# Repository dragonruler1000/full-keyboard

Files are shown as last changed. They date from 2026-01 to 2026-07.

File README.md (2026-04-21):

# full-keyboard
This is a 108 key keyboard that follows the ansi 104 key layout with 4 extra keys above the numpad. It has spots for two rotary encoders and a oled but to start i am going to not include those to reduce cost.

I wanted to make this to allow me to try a mechanical keyboard without needing to spend $200+ for a lowend mechanical keyboard and to give a chance to use QMK firmware.

To make this keyboard for your self upload the gerbers in [/PCB](/PCB) to your prefered pcb site. the case is split into 2 parts the files are in [/CAD](/CAD). firmware is built like any qmk firmware. instructions are in the folder as well. other parts are listed below and in BOM.csv and BOM.ods
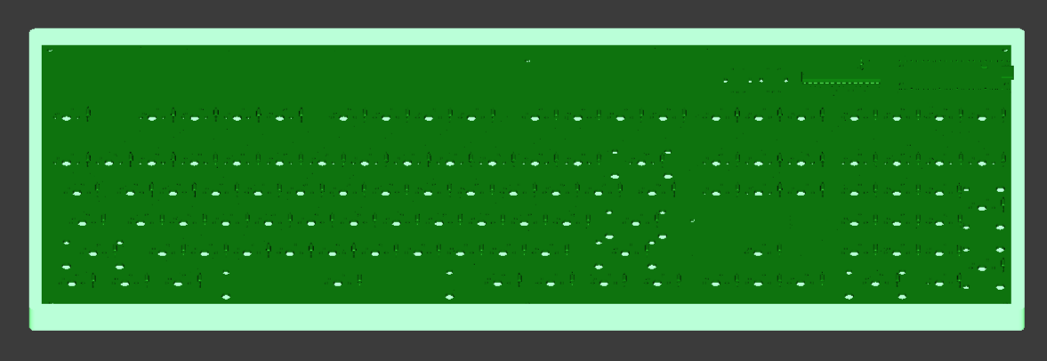
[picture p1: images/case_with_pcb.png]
keyboard in case

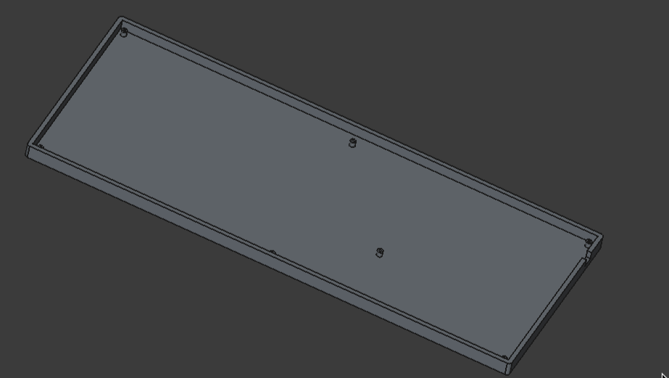
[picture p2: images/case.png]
case

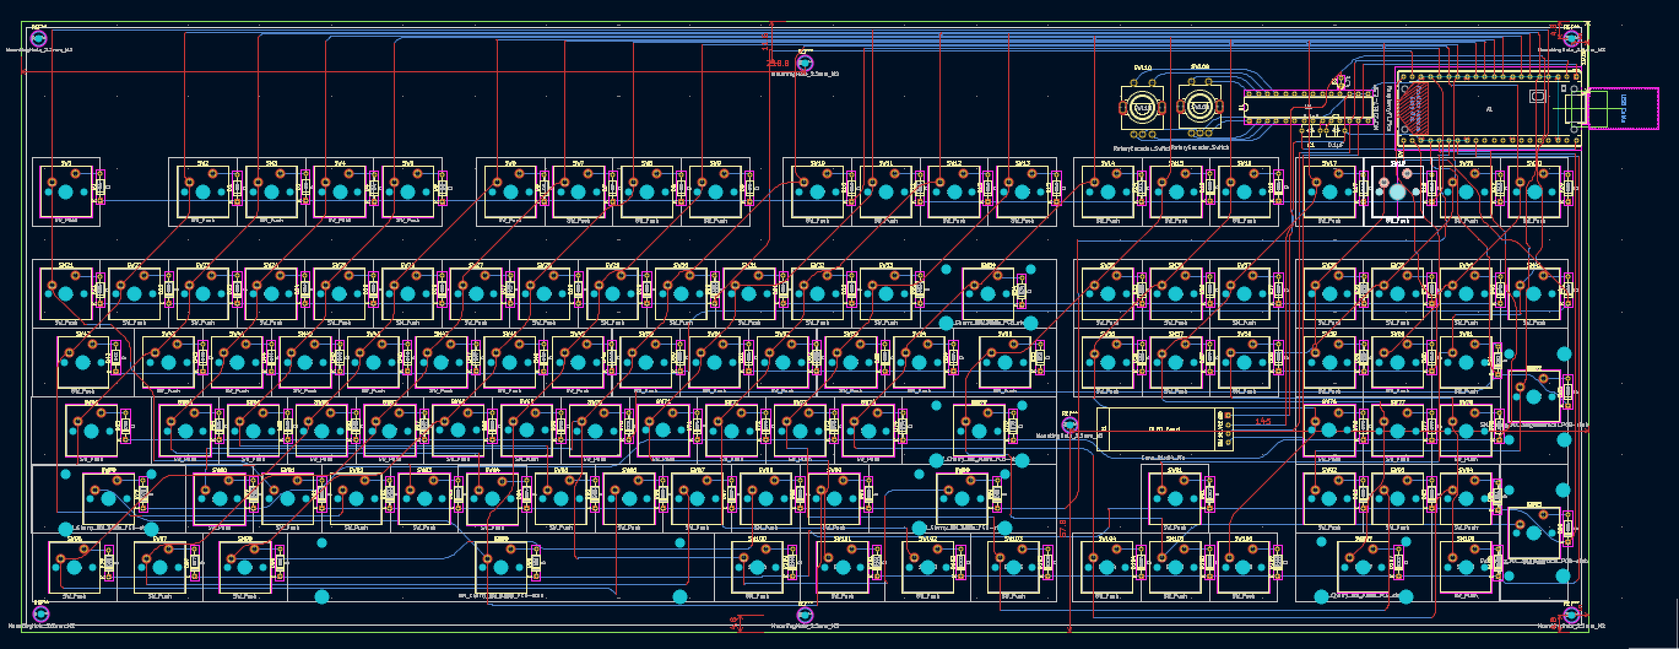
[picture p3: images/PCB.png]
keyboard PCB


Fully soldered keyboard (just need to get the case and keycaps).


BOM:
| Item Count | item name | Unit price $ | Total Price* | Price with discounts* | Link | Running total $* | Running total with coupons* | part number | Notes |
|---|---|---|---|---|---|---|---|---|---|
| 1 | Raspi pico | 5 | 5 | 5 | https://www.adafruit.com/product/5525 | 5.3 | 5.3 | 1 | |
| 110 | 1N4148-t50A diode | 0.0307 | 3.38 | 3.38 | https://www.lcsc.com/product-detail/C895215.html | 8.88 | 8.88 | 2 | packs of 10 |
| 108 | keycaps | 0 | 0 | 0 | https://www.printables.com/model/118708-simple-cherry-mx-keycap | 8.88 | 8.88 | 3 | 1g each can print myself |
| 1 | Outemu(Gaote) Blue Switches  | 21.99 | 21.99 | 21.99 | https://www.amazon.com/gp/product/B0CBSL2Z75 | 32.19 | 32.19 | 4 | pack of 108 price |
| 1 | DUROCK PCB mount stabalizers | 17.99 | 17.99 | 17.99 | https://www.amazon.com/gp/product/B0B2RVN19F?psc=1 | 51.26 | 51.26 | 5 | full set |
| 1 | heatset inserts | 8.99 | 8.99 | 8.99 | https://www.amazon.com/gp/product/B0CS6XJSSL | 60.79 | 60.79 | 6 | |
| 1 | PCB | 35.3 | 35.3 | 35.3 | https://www.jlcpcb.com | 98.21 | 98.21 | 7 | jlcpcb price is cheaper then pcbway before shipping |
| 1 | case | 0 | 0 | 0 | N/A | 98.21 | 98.21 | 8 | print using printing legion |
| 1 | Shipping for PCB | 41.4 | 41.4 | 22.16 | N/A | 142.09 | 121.7 | | First shipping cost is for DHL express second one is for GDL |
| 1 | digikey shipping and tarrifs | 5.36 | 5.36 | 5.36 | N/A | 147.77 | 127.38 | | ±$5 |
| 1 | Adafruit shipping | 5.72 | 5.72 | 5.72 | N/A | 153.83 | 133.44 | | |
| 1 | amazon shipping | 0 | 0 | 0 | N/A | 153.83 | 133.44 | | over min amount for free shipping/have a 30 trial of amazon prime |
| | | | | | | | | | |
| | | | | | | | *Rounded to two decimal places | | |

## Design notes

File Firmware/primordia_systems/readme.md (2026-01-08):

# primordia_systems

primordia_systems

*A short description of the keyboard/project*

* Keyboard Maintainer: [Zachariah Jackson](https://github.com/dragonruler1000)
* Hardware Supported: *The PCBs, controllers supported*
* Hardware Availability: *Links to where you can find this hardware*

Make example for this keyboard (after setting up your build environment):

    make primordia_systems:default

Flashing example for this keyboard:

    make primordia_systems:default:flash

See the [build environment setup](https://docs.qmk.fm/#/getting_started_build_tools) and the [make instructions](https://docs.qmk.fm/#/getting_started_make_guide) for more information. Brand new to QMK? Start with our [Complete Newbs Guide](https://docs.qmk.fm/#/newbs).

## Bootloader

Enter the bootloader in 3 ways:

* **Bootmagic reset**: Hold down the key at (0,0) in the matrix (usually the top left key or Escape) and plug in the keyboard
* **Physical reset button**: Briefly press the button on the back of the PCB - some may have pads you must short instead
* **Keycode in layout**: Press the key mapped to `QK_BOOT` if it is available

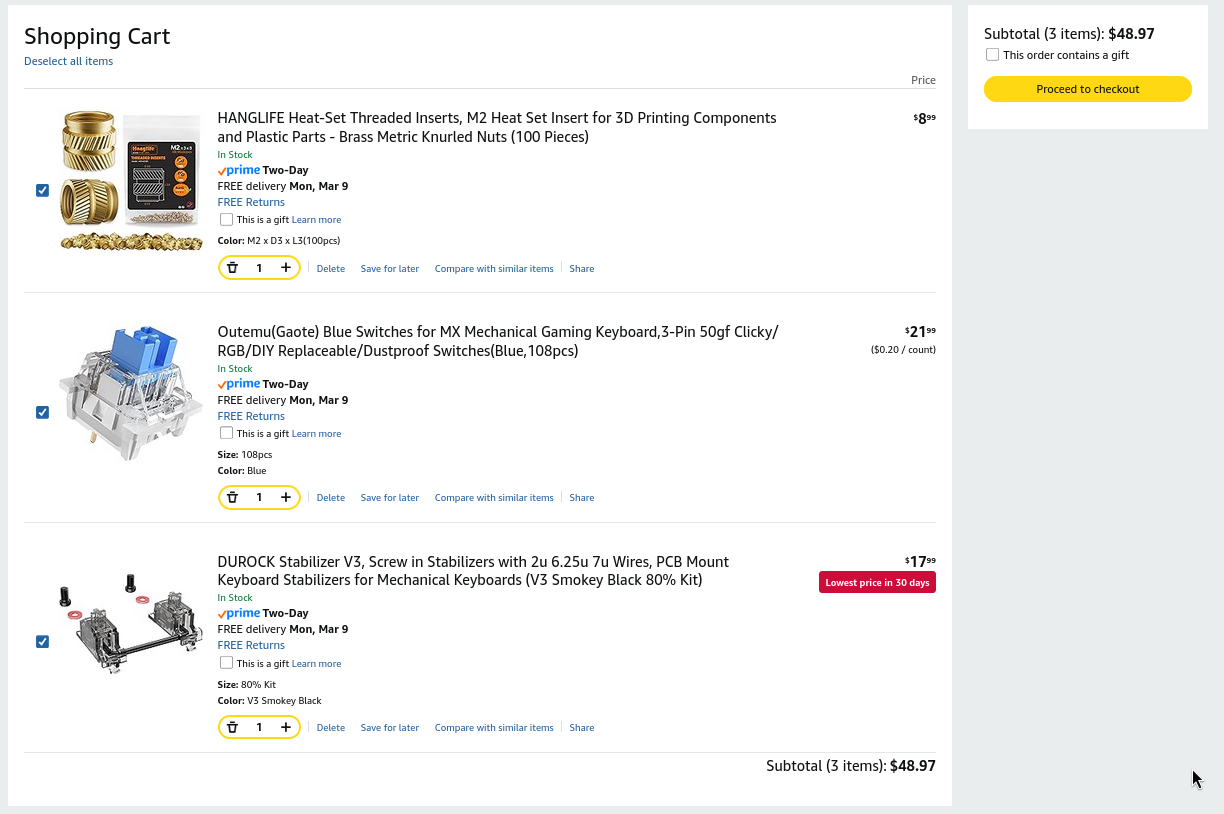
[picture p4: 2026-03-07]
images/cart_screenshots/amazon_cart.png

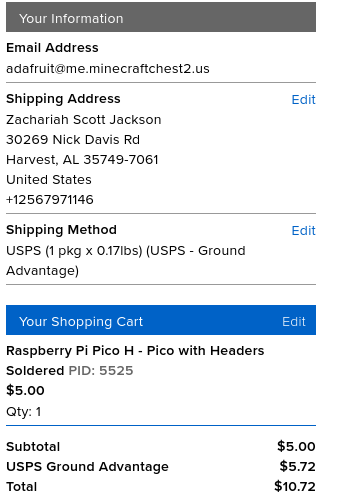
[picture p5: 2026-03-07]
images/cart_screenshots/adafruit_cart.png

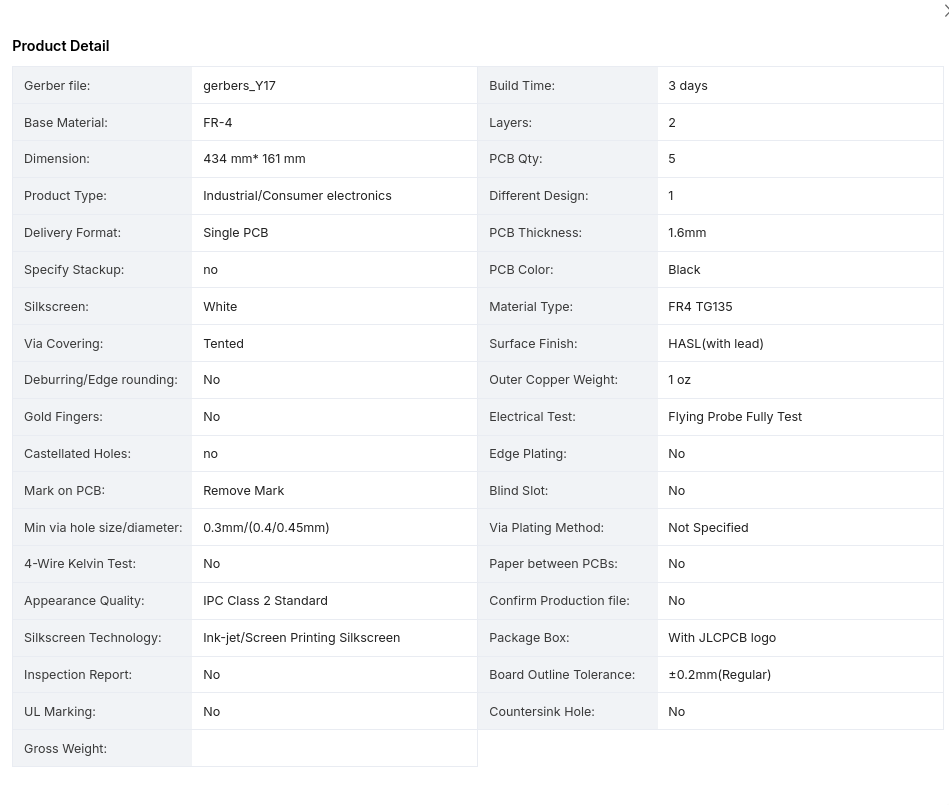
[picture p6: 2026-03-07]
images/cart_screenshots/PCB-details.png

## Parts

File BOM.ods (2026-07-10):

Item Count | item name | Unit price $ | Total Price* | Price with discounts* | Link | Running total $* | Running total with coupons* | part number | Notes
2 | rp2040 | 0.98 | 1.96 | 1.96 | https://jlcpcb.com/partdetail/RaspberryPi-RP2040/C2040 | 2.08 | 2.08 | 1
2 | USB-C port | 0.18 | 0.36 | 0.36 | https://jlcpcb.com/partdetail/Korean_HropartsElec-TYPE_C_31_M12/C165948 | 2.46 | 2.46 | 2
2 | crystal oscillator | 0.07 | 0.14 | 0.14 | https://jlcpcb.com/partdetail/YXC_CrystalOscillators-X322512MSB4SI/C9002 | 2.61 | 2.61 | 3
2 | flash memory |  | 0 | 0 |  | 2.61 | 2.61 | 4
2 | bush button |  | 0 | 0 |  | 2.61 | 2.61 | 5
2 | Schottky diode |  | 0 | 0 |  | 2.61 | 2.61 | 6
2 | LDO |  | 0 | 0 |  | 2.61 | 2.61 | 7
4 | 1uF capacitor |  | 0 | 0 |  | 2.61 | 2.61 | 8
22 | 0.1uf capacitor |  | 0 | 0 |  | 2.61 | 2.61 | 9
4 | 1k Resistors |  | 0 | 0 |  | 2.61 | 2.61 | 10
4 | 27 Resistors |  | 0 | 0 |  | 2.61 | 2.61 | 8
2 | 10K Resistors |  | 0 | 0 |  | 2.61 | 2.61 | 9
4 | 33pF capacitors |  | 0 | 0 |  | 2.61 | 2.61 | 10
2 | 470R Resistors |  | 0 | 0 |  | 2.61 | 2.61 | 8
41 | 5.1k Resistors |  | 0 | 0 |  | 2.61 | 2.61 | 9
2 | LED |  | 0 | 0 |  | 2.61 | 2.61 | 10
2 | 1nF Capacitor |  | 0 | 0 |  | 2.61 | 2.61 | 10
4 | 10uF Capacitors |  | 0 | 0 |  | 2.61 | 2.61 | 10
2 | 100K Resistors |  | 0 | 0 |  | 2.61 | 2.61 | 10
2 | 200K Resistors |  | 0 | 0 |  | 2.61 | 2.61 | 10
2 | 1x3 pin header |  | 0 | 0 |  | 2.61 | 2.61 | 11
4 | 1x20 pin header |  | 0 | 0 |  | 2.61 | 2.61 | 12
 |  |  |  |  |  |  | *Rounded to two decimal places

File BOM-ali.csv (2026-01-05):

Item Count | item name | Unit price $ | Total Price* | Price with discounts* | Link | Running total $* | Running total with coupons* | part number | Notes
1 | Raspi pico | 5 | 5 | 5 | https://www.adafruit.com/product/5525 | 5.3 | 5.3 | 1
0 | MCP23017-E/SP | 2.8633 | 0 | 0 | https://www.lcsc.com/product-detail/C647352.html | 5.3 | 5.3 | 2
0 | DUROCK MX Hotswap PCB Socket | 12.99 | 0 | 0 | https://www.amazon.com/DUROCK-Mechanical-Keyboard-Switches-Hot-Swap/dp/B0B4W9YMGM | 5.3 | 5.3 | 3 | comes in a pack of 110 sockets
110 | 1N4148-t50A diode | 0.0338 | 3.72 | 3.72 | https://www.lcsc.com/product-detail/C895215.html | 9.24 | 9.24 | 4 | packs of 10
0 | 4.7kΩ Resister | 0.0104 | 0 | 0 | https://www.lcsc.com/product-detail/C172560.html | 9.24 | 9.24 | 5
108 | keycaps | 0 | 0 | 0 | https://www.printables.com/model/118708-simple-cherry-mx-keycap | 9.24 | 9.24 | 6 | 1g each can print myself
1 | Gateron G Pro 3.0 Blue Switches | 13.35 | 13.35 | 13.35 | https://www.aliexpress.us/item/3256805690299829.html | 23.39 | 23.39 | 7 | pack of 108 price
0 | rotary encoder | 2.0254 | 0 | 0 | https://www.lcsc.com/product-detail/C470754.html?s_z=n_EC11 | 23.39 | 23.39 | 8
1 | DUROCK PCB mount stabalizers | 16.99 | 16.99 | 16.99 | https://www.aliexpress.us/item/3256803496011237.htm | 41.4 | 41.4 | 9 | full set
1 | PCB | 37.4 | 37.4 | 37.4 | https://www.jlcpcb.com | 81.04 | 81.04 | 10 | jlcpcb price is cheaper then pcbway before shipping
0 | oled display | 2.43 | 0 | 0 | https://www.aliexpress.us/item/3256808041069220.html | 81.04 | 81.04 | 11
0 | pin header for oled | 0.3233 | 0 | 0 | https://www.lcsc.com/product-detail/C19795120.html | 81.04 | 81.04 | 12 | packs of 5
0 | 100nF cap | 0.4264 | 0 | 0 | https://www.lcsc.com/product-detail/C1622885.html | 81.04 | 81.04 | 13
1 | case | 0 | 0 | 0 | https://www.tinkercad.com/things/01yfcJqc3YT-ingenious-bigery-lappi/edit | 81.04 | 81.04 | 14 | print my self/make out of cardboard
1 | Shipping for PCB | 58.5 | 58.5 | 26.32 | N/A | 143.05 | 108.94 |  | First shipping cost is for DHL express second one is for GDL
1 | digikey shipping and tarrifs | 5.36 | 5.36 | 5.36 |  | 148.73 | 114.62 |  | ±$5
1 | Adafruit shipping | 5.99 | 5.99 | 5.99 |  | 155.08 | 120.97
1 | aliexpress shipping | 0 | 0 | 0 |  | 155.08 | 120.97 |  | over min amount for free shipping
 |  |  |  |  |  |  | *Rounded to two decimal places

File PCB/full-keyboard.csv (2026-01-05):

Id | Designator | Footprint | Quantity | Designation | Supplier and ref
1 | SW52,SW47,SW20,SW66,SW64,SW8,SW73,SW106,SW76,SW28,SW31,SW19,SW25,SW54,SW12,SW1,SW11,SW57,SW37,SW18,SW49,SW78,SW27,SW29,SW89,SW70,SW71,SW104,SW80,SW93,SW2,SW77,SW3,SW92,SW14,SW83,SW86,SW10,SW105,SW85,SW30,SW36,SW108,SW7,SW59,SW39,SW48,SW50,SW9,SW44,SW56,SW38,SW74,SW35,SW72,SW22,SW6,SW21,SW58,SW69,SW5,SW87,SW23,SW17,SW60,SW41,SW43,SW53,SW33,SW88,SW26,SW40,SW82,SW51,SW45,SW46,SW67,SW32,SW13,SW15,SW61,SW84,SW91,SW81,SW16,SW68,SW94,SW4,SW24,SW65 | SW_Hotswap_Kailh_MX_1.00u | 90 | SW_Push
2 | D106,D42,D38,D40,D56,D88,D55,D98,D97,D67,D74,D96,D82,D86,D41,D91,D26,D39,D83,D11,D22,D15,D5,D51,D58,D28,D107,D19,D8,D70,D72,D33,D37,D44,D13,D73,D85,D48,D79,D29,D46,D75,D30,D90,D87,D69,D9,D12,D4,D20,D25,D108,D84,D1,D62,D101,D7,D50,D99,D36,D95,D105,D100,D92,D2,D31,D66,D93,D43,D103,D104,D17,D32,D65,D54,D14,D16,D34,D23,D3,D77,D102,D71,D27,D35,D6,D24,D45,D18,D61,D64,D81,D68,D63,D47,D89,D21,D53,D78,D59,D49,D76,D57,D10,D80,D60,D94,D52 | D_DO-35_SOD27_P7.62mm_Horizontal | 108 | D
3 | J1 | SSD1306-0.91-OLED-4pin-128x32 | 1 | Conn_01x04_Pin
4 | SW98,SW97,SW101,SW96,SW100,SW102,SW103 | SW_Hotswap_Kailh_MX_1.25u | 7 | SW_Push
5 | REF**,REF** | SW_Cherry_MX_2.00u_Vertical_PCB-stab | 2 | SW_Cherry_MX_2.00u_Vertical_PCB-stab
6 | REF**,REF** | SW_Cherry_MX_2.25u_PCB-stab | 2 | SW_Cherry_MX_2.25u_PCB-stab
7 | REF** | SW_Cherry_MX_6.25u_PCB-stab | 1 | SW_Cherry_MX_6.25u_PCB-stab
8 | SW62,SW95 | SW_Hotswap_Kailh_MX_2.00u_90deg | 2 | SW_Push
9 | SW107,SW34 | SW_Hotswap_Kailh_MX_2.00u | 2 | SW_Push
10 | SW90 | SW_Hotswap_Kailh_MX_2.75u | 1 | SW_Push
11 | SW109,SW110 | SW-TH_EC11XXXXXXXX | 2 | RotaryEncoder_Switch
12 | SW42,SW55 | SW_Hotswap_Kailh_MX_1.50u | 2 | SW_Push
13 | REF** | SW_Cherry_MX_2.75u_PCB-stab | 1 | SW_Cherry_MX_2.75u_PCB-stab
14 | REF**,REF** | SW_Cherry_MX_2.00u_PCB_stabs | 2 | SW_Cherry_MX_2.00u_PCB_stabs
15 | C1,C2 | CAP-TH_L5.1-W3.2-P5.08-D0.50 | 2 | 0.1µF
16 | U1 | DIP-28_W7.62mm | 1 | MCP23017-E_SP
17 | SW63 | SW_Hotswap_Kailh_MX_1.75u | 1 | SW_Push
18 | SW75,SW79 | SW_Hotswap_Kailh_MX_2.25u | 2 | SW_Push
19 | A1 | RaspberryPi_Pico_Common_THT | 1 | RaspberryPi_Pico
20 | R3 | RES-TH_BD2.5-L4.7-P8.70-D0.5 | 1 | 4.7k
21 | SW99 | SW_Hotswap_Kailh_MX_6.25u | 1 | SW_Push

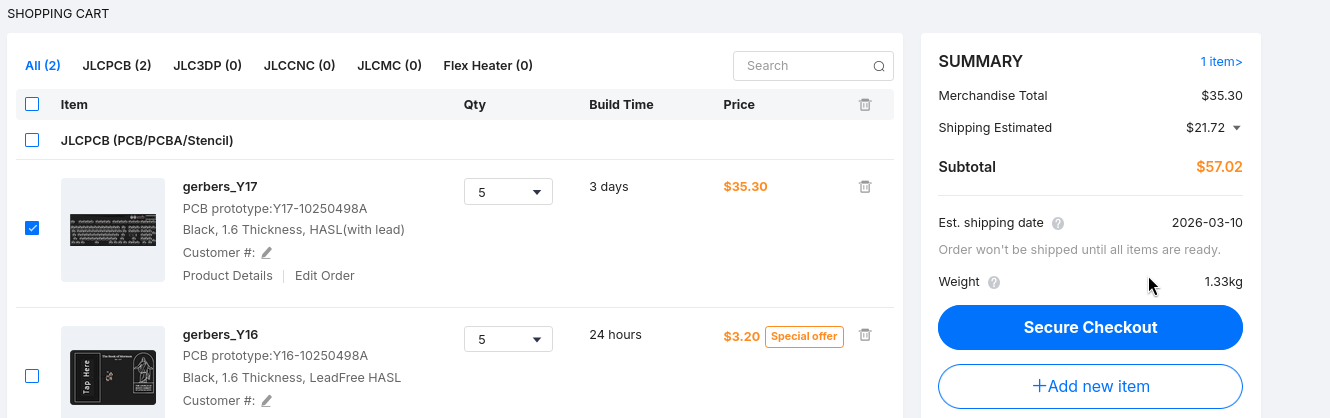
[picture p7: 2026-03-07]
images/cart_screenshots/pcb_cost.png

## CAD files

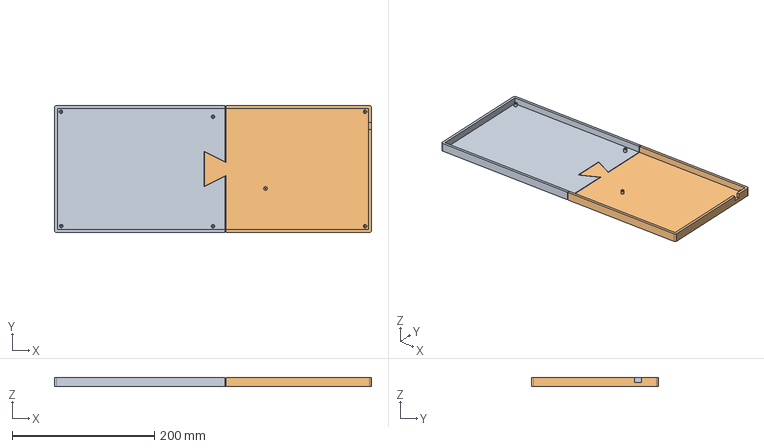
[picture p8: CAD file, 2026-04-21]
CAD/Case_bottom.FCStd
445.6 x 178.4 x 13.1 mm

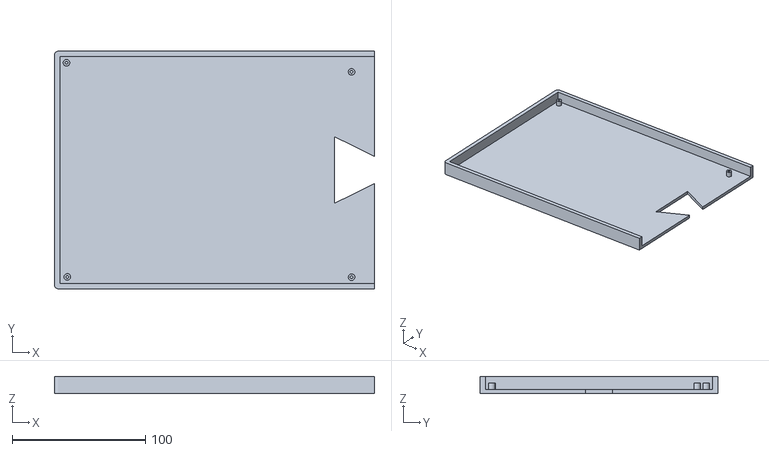
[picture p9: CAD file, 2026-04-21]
CAD/Keyboard-Case/Case_bottom-left.stl
240.0 x 178.4 x 13.1

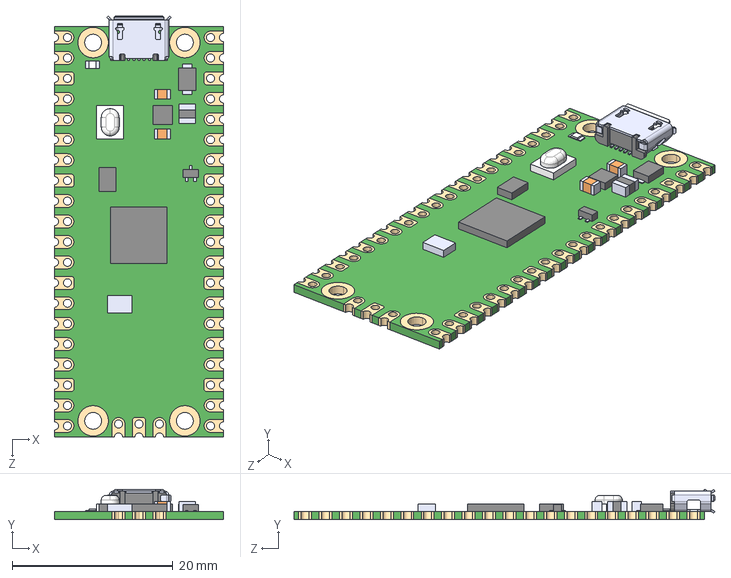
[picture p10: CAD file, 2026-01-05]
PCB/RASPBERRY_PI_PICO/RASPBERRY_PI_PICO.step
21.0 x 3.73 x 52.3 mm

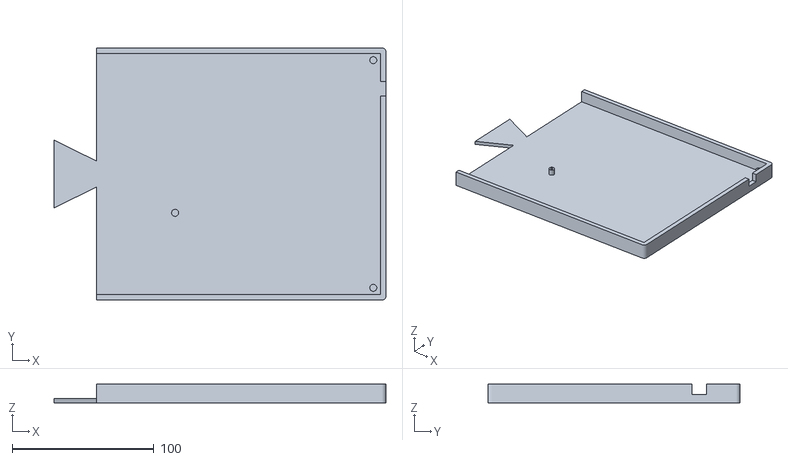
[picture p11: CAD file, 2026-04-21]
CAD/Keyboard-Case/Case_bottom-right.stl
234.6 x 178.4 x 13.1

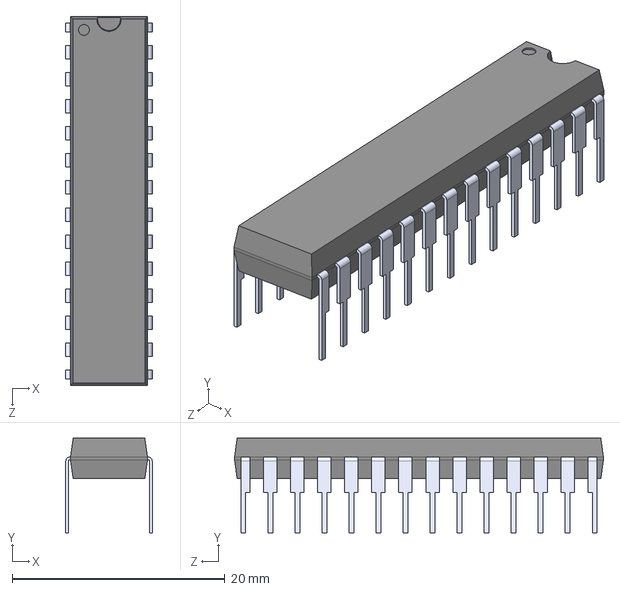
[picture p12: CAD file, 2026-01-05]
PCB/MCP23017_E_SP/MCP23017-E_SP.step
8.13 x 8.89 x 34.7 mm

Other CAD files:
CAD/Case_bottom-Body.step
CAD/Case_bottom-Body.3mf
CAD/Case_bottom-Body.stl

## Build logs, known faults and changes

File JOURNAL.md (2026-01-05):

<!--
  This journal is auto generated by Hack Club Blueprint.
-->

## 11/9/2025 - Setup the basics for the keyboard schematic  

_Time spent: 1.5h_  

I got the basics set up. so i have all 108 switches (subject to change) layed out and connected to the Pico. i have gotten most of the way on setting up the IO exstention board i just need to figure out where the ground pin on the symbol is and it is finished. i also have the models for all the symbols but the diodes assigned. i am going with a hybrid hot swap base so i can swap between MX Kalih and Choc switches with out much hassle.


## 12/4/2025 - Finnished the schematic.  

_Time spent: 3.0h_  

finished making the schematic for the keyboard. the fun part was adding the 108 LEDs plus figuring out if i had the correct pins connected to the i2c exspander i was using.


## 12/5/2025 11 AM - Made the BOM  

_Time spent: 1.0h_  

Finished finding all the parts i will need. turned out the the first hotswap sockets i found even though they where ~$3.40 a pack sense they came in packs of ten they would have been ~$50 of the total price after looking on amazon for some i found a pack of 110 for $12.99.BOM

## 12/5/2025 10 PM - Laying out the PCB  

_Time spent: 3.0h_  

I started working on laying out the PCB. i made a layout using keyboard layout editor witch i am using to position my keys. I am also wanting each row and colom on the keyboard to match the place in the keyboard (so the function keys are row one and so forth) so i needed to redo my grid on the schematic side witch i am still working on. I also found stablizers that i might end up using that will depend if i can find a kit that will work for cheaper.


## 12/7/2025 11 AM - layed out the key switches  

_Time spent: 2.0h_  

i got the switches layout out on both the PCB and the schematic. i was having the schematic side layout out the same to make the traces look better. still looking for a footprint for the stabilizers.


## 12/7/2025 9 PM - changed matrix layout  

_Time spent: 3.0h_  

After i finished doing the 21x6 matrix i realized that i don't have enough GPIO pins to do that so i had to go down to a 19x6 matrix. then i was making sure that i had the correct footpints for the key switches to make sure the spaceing was correct. i looked through like 6 libraries before i realised i had grabed the keyswitch footprint library from the plugin and content manager witch works but it it doesnt have the stablizers mounting holes i need to use a pcb mount screwd in stablizer so that is what i am going to work on tomorrow is the tablizer mounting holes.

## 12/23/2025 - mostly routed the pcb  

_Time spent: 5.0h_  

spent a little while figuring out the best way to make my matrix fit on the pi or split it so the colums are on the pico and the rows are on the i2c expander. i ended up switching to a 10x11 matrix (10 col x 11 row) witch fit on the pico with out any issues. i have also dropped the rgb because i am planning on using a 2x4x8 and osb to make the case so the rgb probably wouldn't be viable any ways and it makes routing easier because i dont have to worry about routing the power and data for the leds around the traces for the rows and columns.

## 12/24/2025 - did some BOM optimiting  

_Time spent: 0.5h_  

i did some BOM optimizing with help from ChatGPT (which wasn't much help) so i think now my bom is as optimized as i can make it unless i want to switch to a 3d printed case. it turns out that i only need one pull up resister because the internal pullups in the MCP23017 work according to the i2c standard.

## 12/29/2025 - Made the case  

_Time spent: 1.0h_  

i made the case for the keyboard i am planning on doing a Plateless Mount style keyboard that uses the foam sandwich method to keep the keyboard from moving around. doing a plateless mount wasn't originally my plan, hence the pins to hold the top plate in place on the case design, but i didn't want to deal with editing the plate dxf from ai03 plate generator to make it work with my design. like the case for my 8-bit pc it was split in half and each half is the same just needing to be printed twice and rotated 180 degrees.
2025-12-29-231431_hyprshot
Now i just need to fit my git repo currently most of the stuff is under git-lfs and try to cut down on costs on my BOM.  

## 1/4/2026 - started reroutingthe pcb and BOM optimazation  

_Time spent: 2.0h_  

rerouting the pcb to not use hotswap sockets to save on cost. I also dropped purchasing the rotary encoders, oled, and i2c expanders for the time being for the same reasion so for the time being i am only going to get the keyswitches and stabs. i am still over budget but not as much as it was before.
BOM

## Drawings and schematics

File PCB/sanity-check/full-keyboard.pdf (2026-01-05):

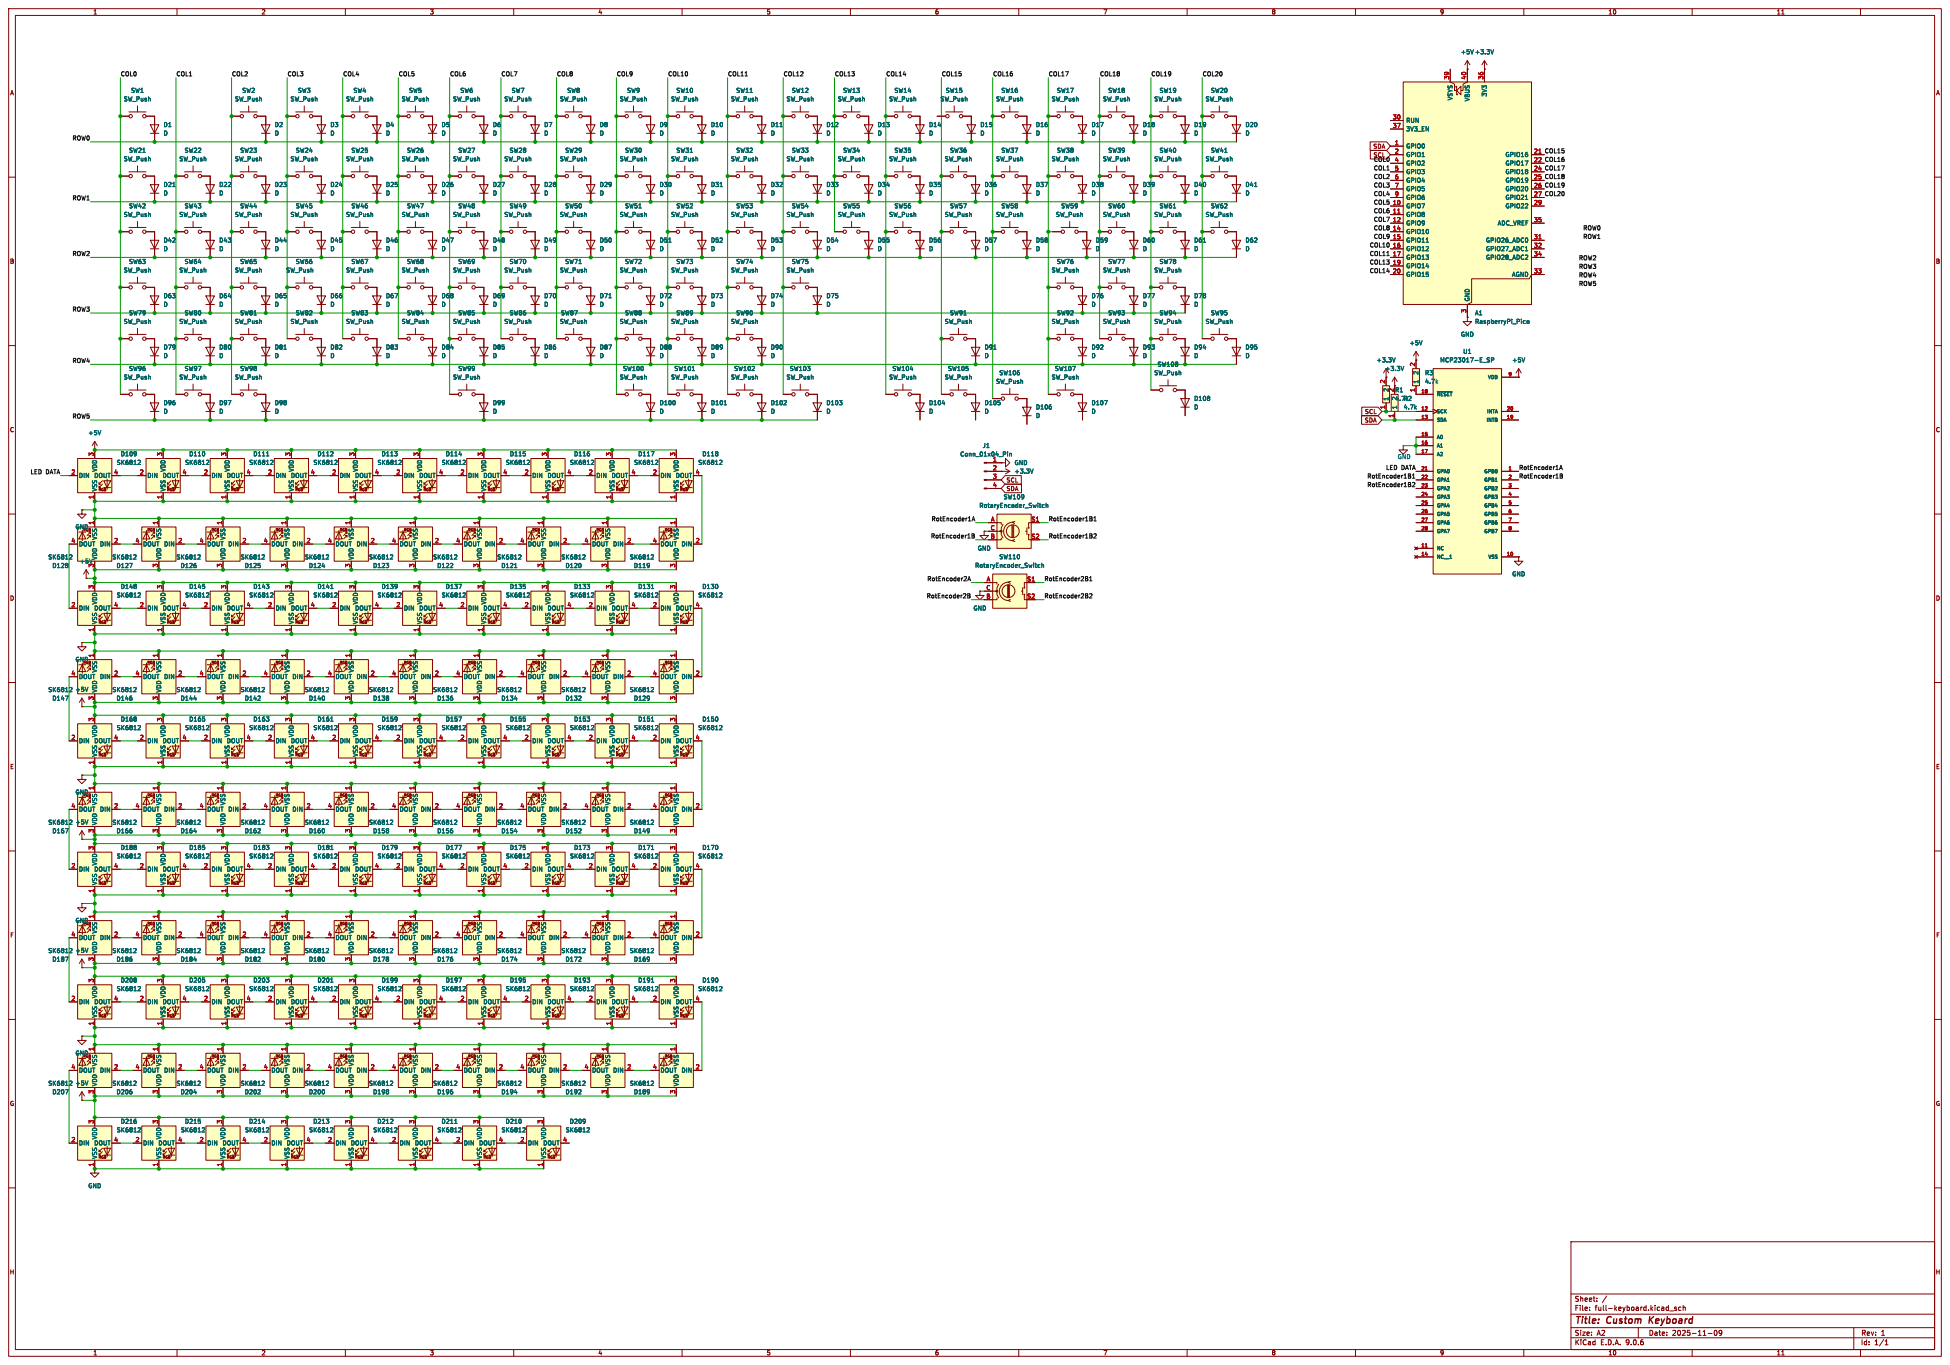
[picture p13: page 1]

1 DOUT 4 D167 SK6812 GND RGB DIN 2 VDD

1 DOUT 4 D192 SK6812 GNDRGB DIN 2 VDD

File: full-keyboard.kicad_sch Sheet: /

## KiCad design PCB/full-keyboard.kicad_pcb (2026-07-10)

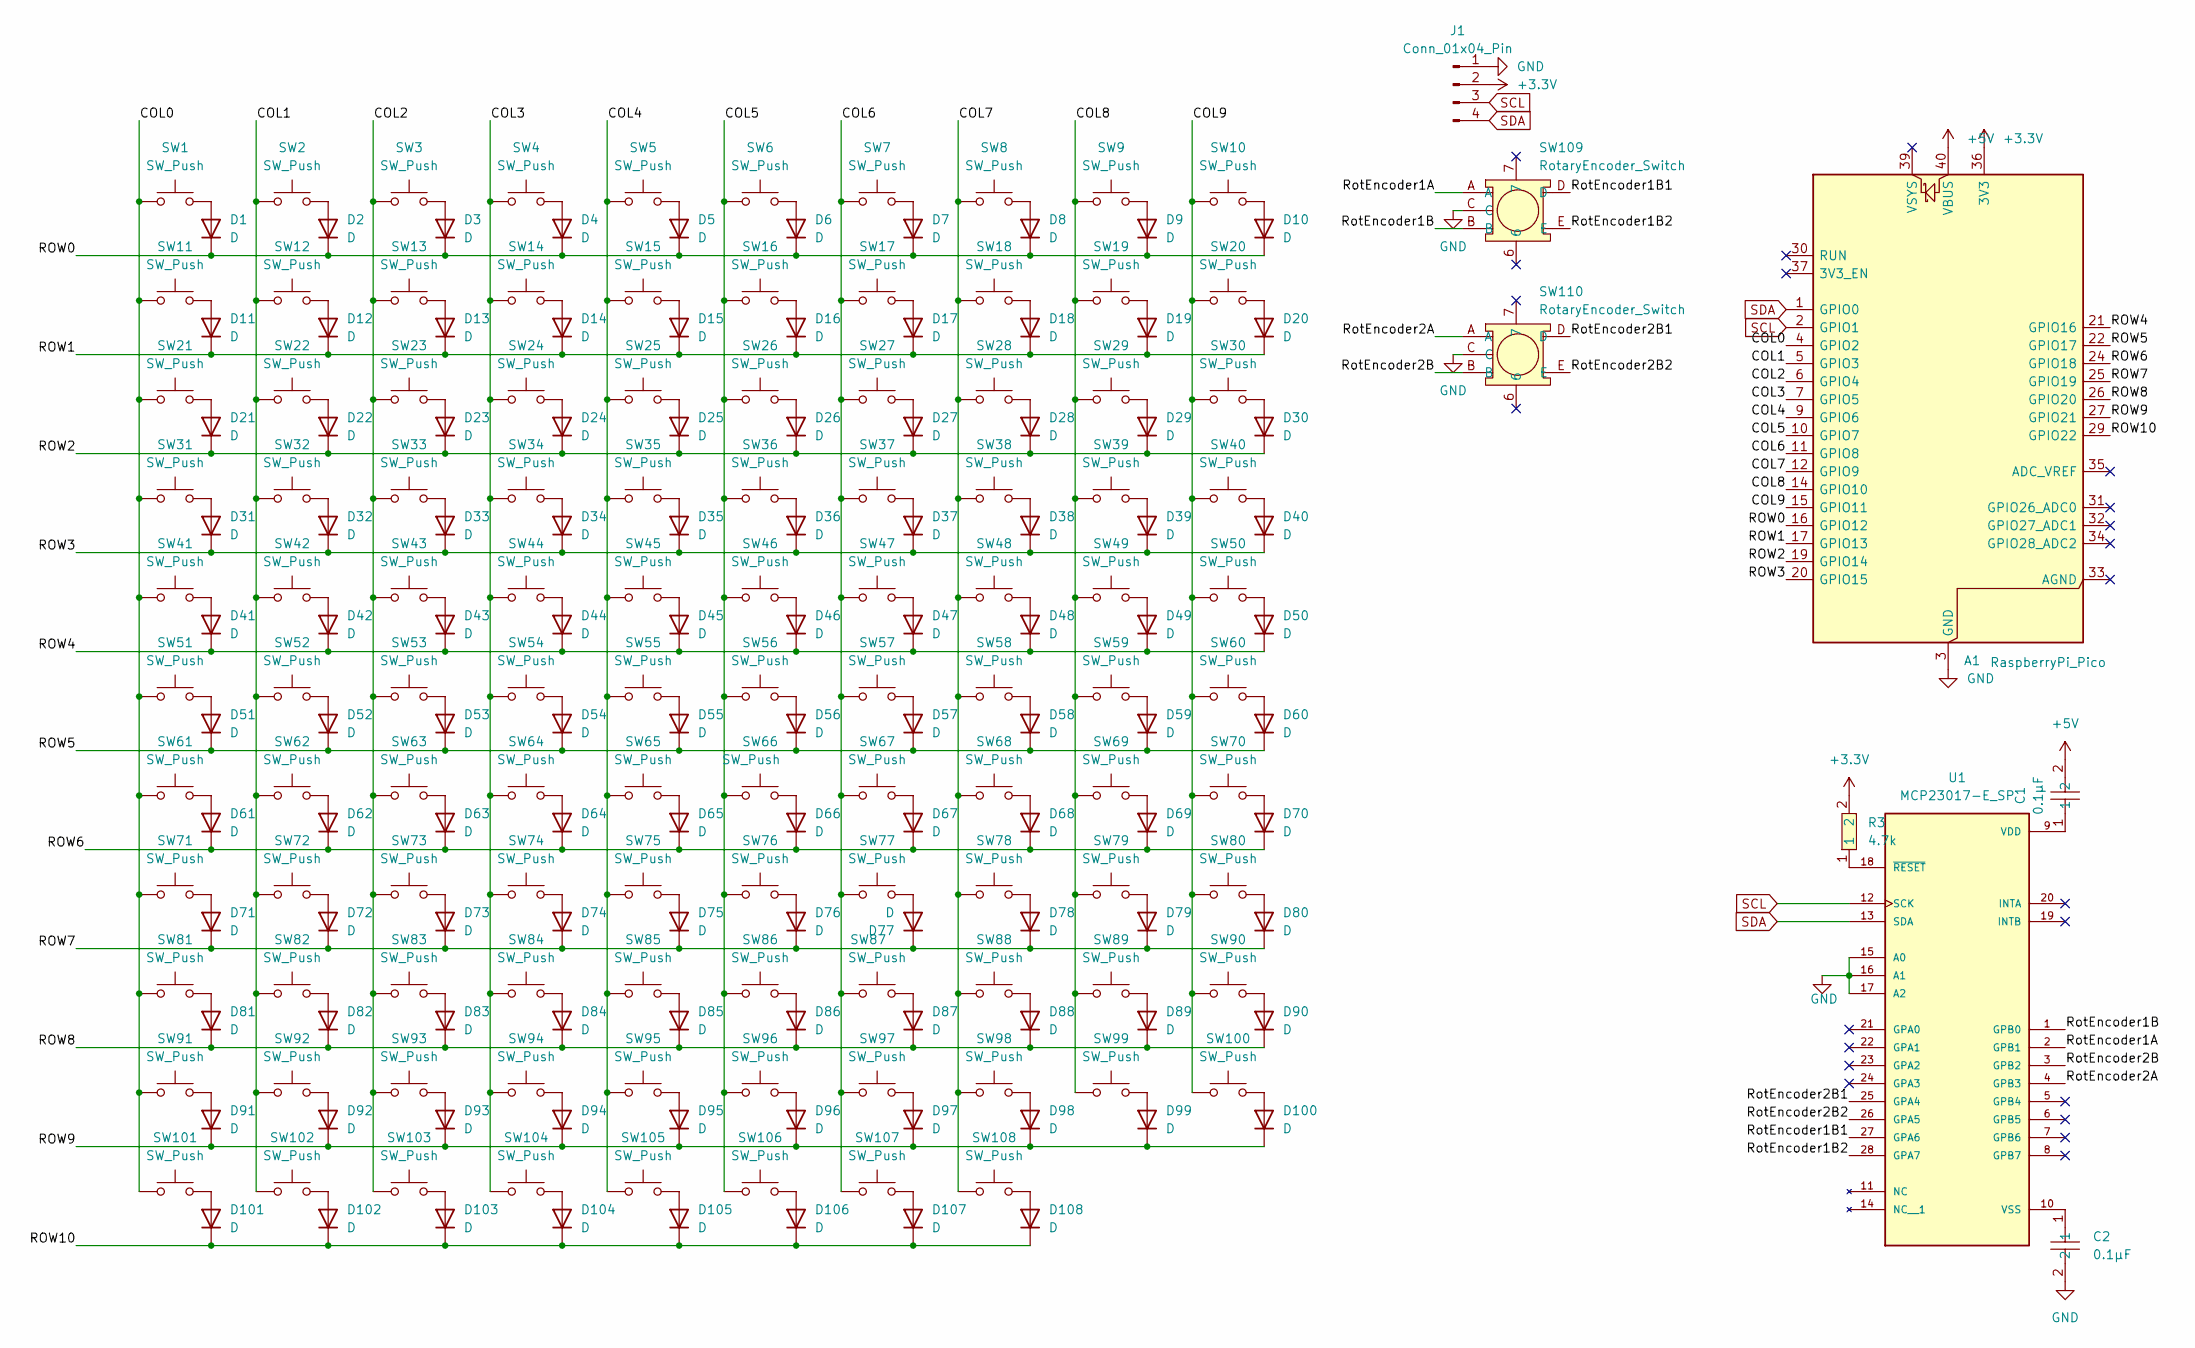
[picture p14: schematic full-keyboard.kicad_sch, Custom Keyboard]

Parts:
A1: RaspberryPi_Pico; RaspberryPi_Pico_Common_THT
C1, C2: 0.1µF; CAP-TH_L5.1-W3.2-P5.08-D0.50; LCSC Part C1622885
D1, D2, D3, D4, D5, D6, D7, D8, D9, D10, D11, D12, D13, D14, D15, D16, D17, D18, D19, D20, D21, D22, D23, D24, D25, D26, D27, D28, D29, D30, D31, D32, D33, D34, D35, D36, D37, D38, D39, D40, D41, D42, D43, D44, D45, D46, D47, D48, D49, D50, D51, D52, D53, D54, D55, D56, D57, D58, D59, D60, D61, D62, D63, D64, D65, D66, D67, D68, D69, D70, D71, D72, D73, D74, D75, D76, D77, D78, D79, D80, D81, D82, D83, D84, D85, D86, D87, D88, D89, D90, D91, D92, D93, D94, D95, D96, D97, D98, D99, D100, D101, D102, D103, D104, D105, D106, D107, D108: D; D_DO-35_SOD27_P7.62mm_Horizontal
J1: Conn_01x04_Pin; SSD1306-0.91-OLED-4pin-128x32
R3: 4.7k; RES-TH_BD2.5-L4.7-P8.70-D0.5; LCSC Part C172560
SW1, SW2, SW3, SW4, SW5, SW6, SW7, SW8, SW9, SW10, SW11, SW12, SW13, SW14, SW15, SW16, SW17, SW18, SW19, SW20, SW21, SW22, SW23, SW24, SW25, SW26, SW27, SW28, SW29, SW30, SW31, SW32, SW33, SW35, SW36, SW37, SW38, SW39, SW40, SW41, SW43, SW44, SW45, SW46, SW47, SW48, SW49, SW50, SW51, SW52, SW53, SW54, SW56, SW57, SW58, SW59, SW60, SW61, SW64, SW65, SW66, SW67, SW68, SW69, SW70, SW71, SW72, SW73, SW74, SW76, SW77, SW78, SW80, SW81, SW82, SW83, SW84, SW85, SW86, SW87, SW88, SW89, SW91, SW92, SW93, SW94, SW104, SW105, SW106, SW108: SW_Push; SW_Hotswap_Kailh_MX_1.00u
SW34, SW107: SW_Push; SW_Hotswap_Kailh_MX_2.00u
SW42, SW55: SW_Push; SW_Hotswap_Kailh_MX_1.50u
SW62, SW95: SW_Push; SW_Hotswap_Kailh_MX_2.00u_90deg
SW63: SW_Push; SW_Hotswap_Kailh_MX_1.75u
SW75, SW79: SW_Push; SW_Hotswap_Kailh_MX_2.25u
SW90: SW_Push; SW_Hotswap_Kailh_MX_2.75u
SW96, SW97, SW98, SW100, SW101, SW102, SW103: SW_Push; SW_Hotswap_Kailh_MX_1.25u
SW99: SW_Push; SW_Hotswap_Kailh_MX_6.25u
SW109, SW110: RotaryEncoder_Switch; SW-TH_EC11XXXXXXXX; LCSC Part C470754
U1: MCP23017-E_SP; DIP-28_W7.62mm; PARTREV D

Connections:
+3.3V: A1.36 (3V3), J1.2, R3.2
+5V: A1.40 (VBUS), C1.2
/COL0: A1.4 (GPIO2), SW1.1, SW11.1, SW21.1, SW31.1, SW41.1, SW51.1, SW61.1, SW71.1, SW81.1, SW91.1, SW101.1
/COL1: A1.5 (GPIO3), SW2.1, SW12.1, SW22.1, SW32.1, SW42.1, SW52.1, SW62.1, SW72.1, SW82.1, SW92.1, SW102.1
/COL2: A1.6 (GPIO4), SW3.1, SW13.1, SW23.1, SW33.1, SW43.1, SW53.1, SW63.1, SW73.1, SW83.1, SW93.1, SW103.1
/COL3: A1.7 (GPIO5), SW4.1, SW14.1, SW24.1, SW34.1, SW44.1, SW54.1, SW64.1, SW74.1, SW84.1, SW94.1, SW104.1
/COL4: A1.9 (GPIO6), SW5.1, SW15.1, SW25.1, SW35.1, SW45.1, SW55.1, SW65.1, SW75.1, SW85.1, SW95.1, SW105.1
/COL5: A1.10 (GPIO7), SW6.1, SW16.1, SW26.1, SW36.1, SW46.1, SW56.1, SW66.1, SW76.1, SW86.1, SW96.1, SW106.1
/COL6: A1.11 (GPIO8), SW7.1, SW17.1, SW27.1, SW37.1, SW47.1, SW57.1, SW67.1, SW77.1, SW87.1, SW97.1, SW107.1
/COL7: A1.12 (GPIO9), SW8.1, SW18.1, SW28.1, SW38.1, SW48.1, SW58.1, SW68.1, SW78.1, SW88.1, SW98.1, SW108.1
/COL8: A1.14 (GPIO10), SW9.1, SW19.1, SW29.1, SW39.1, SW49.1, SW59.1, SW69.1, SW79.1, SW89.1, SW99.1
/COL9: A1.15 (GPIO11), SW10.1, SW20.1, SW30.1, SW40.1, SW50.1, SW60.1, SW70.1, SW80.1, SW90.1, SW100.1
/ROW0: A1.16 (GPIO12), D1.1 (K), D2.1 (K), D3.1 (K), D4.1 (K), D5.1 (K), D6.1 (K), D7.1 (K), D8.1 (K), D9.1 (K), D10.1 (K)
/ROW1: A1.17 (GPIO13), D11.1 (K), D12.1 (K), D13.1 (K), D14.1 (K), D15.1 (K), D16.1 (K), D17.1 (K), D18.1 (K), D19.1 (K), D20.1 (K)
/ROW2: A1.19 (GPIO14), D21.1 (K), D22.1 (K), D23.1 (K), D24.1 (K), D25.1 (K), D26.1 (K), D27.1 (K), D28.1 (K), D29.1 (K), D30.1 (K)
/ROW3: A1.20 (GPIO15), D31.1 (K), D32.1 (K), D33.1 (K), D34.1 (K), D35.1 (K), D36.1 (K), D37.1 (K), D38.1 (K), D39.1 (K), D40.1 (K)
/ROW4: A1.21 (GPIO16), D41.1 (K), D42.1 (K), D43.1 (K), D44.1 (K), D45.1 (K), D46.1 (K), D47.1 (K), D48.1 (K), D49.1 (K), D50.1 (K)
/ROW5: A1.22 (GPIO17), D51.1 (K), D52.1 (K), D53.1 (K), D54.1 (K), D55.1 (K), D56.1 (K), D57.1 (K), D58.1 (K), D59.1 (K), D60.1 (K)
/ROW6: A1.24 (GPIO18), D61.1 (K), D62.1 (K), D63.1 (K), D64.1 (K), D65.1 (K), D66.1 (K), D67.1 (K), D68.1 (K), D69.1 (K), D70.1 (K)
/ROW7: A1.25 (GPIO19), D71.1 (K), D72.1 (K), D73.1 (K), D74.1 (K), D75.1 (K), D76.1 (K), D77.1 (K), D78.1 (K), D79.1 (K), D80.1 (K)
/ROW8: A1.26 (GPIO20), D81.1 (K), D82.1 (K), D83.1 (K), D84.1 (K), D85.1 (K), D86.1 (K), D87.1 (K), D88.1 (K), D89.1 (K), D90.1 (K)
/ROW9: A1.27 (GPIO21), D91.1 (K), D92.1 (K), D93.1 (K), D94.1 (K), D95.1 (K), D96.1 (K), D97.1 (K), D98.1 (K), D99.1 (K), D100.1 (K)
/ROW10: A1.29 (GPIO22), D101.1 (K), D102.1 (K), D103.1 (K), D104.1 (K), D105.1 (K), D106.1 (K), D107.1 (K), D108.1 (K)
/RotEncoder1A: SW109.A, U1.2 (GPB1)
/RotEncoder1B: SW109.B, U1.1 (GPB0)
/RotEncoder1B1: SW109.D, U1.27 (GPA6)
/RotEncoder1B2: SW109.E, U1.28 (GPA7)
/RotEncoder2A: SW110.A, U1.4 (GPB3)
/RotEncoder2B: SW110.B, U1.3 (GPB2)
/RotEncoder2B1: SW110.D, U1.25 (GPA4)
/RotEncoder2B2: SW110.E, U1.26 (GPA5)
GND: A1.3 (GND), A1.8 (GND), A1.13 (GND), A1.18 (GND), A1.23 (GND), A1.28 (GND), A1.38 (GND), C2.2, J1.1, SW109.C, SW110.C, U1.15 (A0), U1.16 (A1), U1.17 (A2)
unnamed: D1.2 (A), SW1.2
unnamed: D2.2 (A), SW2.2
unnamed: D3.2 (A), SW3.2
unnamed: D4.2 (A), SW4.2
unnamed: D5.2 (A), SW5.2
unnamed: D6.2 (A), SW6.2
unnamed: D7.2 (A), SW7.2
unnamed: D8.2 (A), SW8.2
unnamed: D9.2 (A), SW9.2
unnamed: D10.2 (A), SW10.2
unnamed: D11.2 (A), SW11.2
unnamed: D12.2 (A), SW12.2
unnamed: D13.2 (A), SW13.2
unnamed: D14.2 (A), SW14.2
unnamed: D15.2 (A), SW15.2
unnamed: D16.2 (A), SW16.2
unnamed: D17.2 (A), SW17.2
unnamed: D18.2 (A), SW18.2
unnamed: D19.2 (A), SW19.2
unnamed: D20.2 (A), SW20.2
unnamed: D21.2 (A), SW21.2
unnamed: D22.2 (A), SW22.2
unnamed: D23.2 (A), SW23.2
unnamed: D24.2 (A), SW24.2
unnamed: D25.2 (A), SW25.2
unnamed: D26.2 (A), SW26.2
unnamed: D27.2 (A), SW27.2
unnamed: D28.2 (A), SW28.2
unnamed: D29.2 (A), SW29.2
unnamed: D30.2 (A), SW30.2
unnamed: D31.2 (A), SW31.2
unnamed: D32.2 (A), SW32.2
unnamed: D33.2 (A), SW33.2
unnamed: D34.2 (A), SW34.2
unnamed: D35.2 (A), SW35.2
unnamed: D36.2 (A), SW36.2
unnamed: D37.2 (A), SW37.2
unnamed: D38.2 (A), SW38.2
unnamed: D39.2 (A), SW39.2
unnamed: D40.2 (A), SW40.2
unnamed: D41.2 (A), SW41.2
unnamed: D42.2 (A), SW42.2
unnamed: D43.2 (A), SW43.2
unnamed: D44.2 (A), SW44.2
unnamed: D45.2 (A), SW45.2
unnamed: D46.2 (A), SW46.2
unnamed: D47.2 (A), SW47.2
unnamed: D48.2 (A), SW48.2
unnamed: D49.2 (A), SW49.2
unnamed: D50.2 (A), SW50.2
unnamed: D51.2 (A), SW51.2
unnamed: D52.2 (A), SW52.2
unnamed: D53.2 (A), SW53.2
unnamed: D54.2 (A), SW54.2
unnamed: D55.2 (A), SW55.2
unnamed: D56.2 (A), SW56.2
unnamed: D57.2 (A), SW57.2
unnamed: D58.2 (A), SW58.2
unnamed: D59.2 (A), SW59.2
unnamed: D60.2 (A), SW60.2
unnamed: D61.2 (A), SW61.2
unnamed: D62.2 (A), SW62.2
unnamed: D63.2 (A), SW63.2
unnamed: D64.2 (A), SW64.2
unnamed: D65.2 (A), SW65.2
unnamed: D66.2 (A), SW66.2
unnamed: D67.2 (A), SW67.2
unnamed: D68.2 (A), SW68.2
unnamed: D69.2 (A), SW69.2
unnamed: D70.2 (A), SW70.2
unnamed: D71.2 (A), SW71.2
unnamed: D72.2 (A), SW72.2
unnamed: D73.2 (A), SW73.2
unnamed: D74.2 (A), SW74.2
unnamed: D75.2 (A), SW75.2
unnamed: D76.2 (A), SW76.2
unnamed: D77.2 (A), SW77.2
unnamed: D78.2 (A), SW78.2
unnamed: D79.2 (A), SW79.2
unnamed: D80.2 (A), SW80.2
unnamed: D81.2 (A), SW81.2
unnamed: D82.2 (A), SW82.2
unnamed: D83.2 (A), SW83.2
unnamed: D84.2 (A), SW84.2
unnamed: D85.2 (A), SW85.2
unnamed: D86.2 (A), SW86.2
unnamed: D87.2 (A), SW87.2
unnamed: D88.2 (A), SW88.2
unnamed: D89.2 (A), SW89.2
unnamed: D90.2 (A), SW90.2
unnamed: D91.2 (A), SW91.2
unnamed: D92.2 (A), SW92.2
unnamed: D93.2 (A), SW93.2
unnamed: D94.2 (A), SW94.2
unnamed: D95.2 (A), SW95.2
unnamed: D96.2 (A), SW96.2
unnamed: D97.2 (A), SW97.2
unnamed: D98.2 (A), SW98.2
unnamed: D99.2 (A), SW99.2
unnamed: D100.2 (A), SW100.2
unnamed: D101.2 (A), SW101.2
unnamed: D102.2 (A), SW102.2
unnamed: D103.2 (A), SW103.2
unnamed: D104.2 (A), SW104.2
unnamed: D105.2 (A), SW105.2
unnamed: D106.2 (A), SW106.2
unnamed: D107.2 (A), SW107.2
unnamed: D108.2 (A), SW108.2
unnamed: C1.1, U1.9 (VDD)
unnamed: C2.1, U1.10 (VSS)
unnamed: R3.1, U1.18 (~RESET)
SCL: A1.2 (GPIO1), J1.3, U1.12 (SCK)
SDA: A1.1 (GPIO0), J1.4, U1.13 (SDA)

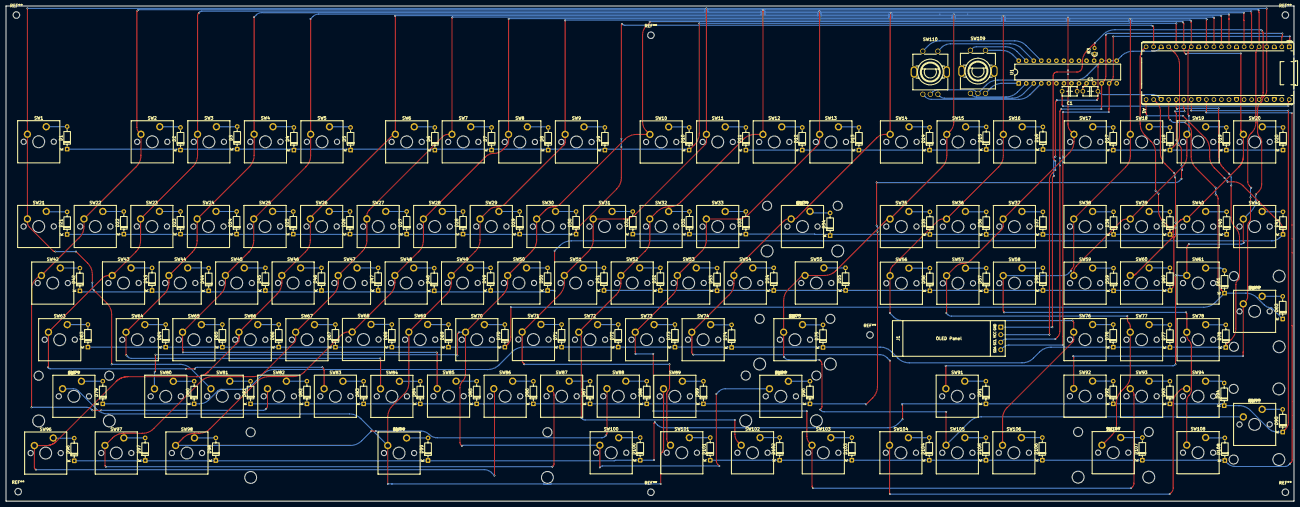
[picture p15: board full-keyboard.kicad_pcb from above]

Board: 2 copper layers, 434.0 x 166.8 mm, 224 parts (0 on the bottom side), 145 nets.

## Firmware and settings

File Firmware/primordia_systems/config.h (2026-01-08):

// I2C Configuration
#define I2C_DRIVER I2CD0
#define I2C1_SDA_PIN GP0
#define I2C1_SCL_PIN GP1

// MCP23017 Configuration
#define MCP23017_I2C_ADDRESS 0x20  // Default address, adjust if different

// Encoder pins on MCP23017
// Encoder 0: GPB0 (A), GPB1 (B)
// Encoder 1: GPB2 (A), GPB3 (B)
#define ENCODERS_PAD_A { GPB1, GPB3 }
#define ENCODERS_PAD_B { GPB0, GPB2 }
#define ENCODER_RESOLUTION 4

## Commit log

2026-01-05 switching to a new repo to fix git lfs problems
    [BOM-ali.csv, BOM-ali.ods, BOM.csv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]
2026-01-07 added case model
    [BOM.ods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]
2026-01-08 add images and BOM to readme
    [BOM.csv, BOM.ods]
2026-01-08 updated bom to use parts from digikey for cheaper overall cost
    [BOM.csv, BOM.ods]
2026-01-17 update BOM to use cheaper parts from aliexpress
    [BOM.csv, BOM.ods]
2026-01-17 update item names
    [BOM.csv, BOM.ods]
2026-02-18 Revise BOM with updated item information
    Updated BOM with new item details and prices.
2026-02-18 added cart images and updated bom to match current prices
    [BOM.csv, BOM.ods]
2026-02-22 switched to case made by TurboCase for a nicer case with standoff.
    [full-keyboard.kicad_pcb, full-keyboard.scad, keyboard-case.stl]
2026-03-07 made the case in FreeCAD and moved the locations of two of the mounting holes and added a 7th
    [Case_bottom-Body.3mf, Case_bottom-Body.step, Case_bottom.FCStd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]
2026-03-07 added stl files to git lfs
2026-03-07 removed file that i dont need to include
    [full-keyboard.stl]
2026-03-07 teying stuff
    [full-keyboard.stl]
2026-03-07 \updated gerbers
2026-03-07 updated BOM to match current pricing of parts
    [BOM.csv, BOM.ods, Case_bottom.FCStd]
2026-03-07 updated cart images and added heatset inserts to BOM
    [BOM.csv, BOM.ods]
2026-04-10 Revise keyboard case details and add images
    Updated README to reflect case design changes and added images.
2026-04-21 Updated PCB to add standoff support and made a case to support the keyboard with standoffsx
    [BOM.ods, Case_bottom-Body.stl, Case_bottom-left.stl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]
2026-04-21 update CAD info in README
2026-07-10 dont quite remember
    [BOM.ods, Case_bottom-left.stl, Case_bottom-right.stl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]
